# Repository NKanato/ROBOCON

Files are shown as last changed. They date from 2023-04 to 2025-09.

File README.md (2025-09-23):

# ROBOCON
ロボコン用リポジトリです。<br>
2023KYOROBO：2023年度九州共同ロボコン出場時の回路及びプログラム<br>
2023HONROBO：2023年度高専ロボコン出場時の回路及びプログラム<br>
の成果物を入れています。<br>
<br><br>
# 画像
2023九州共同ロボコン
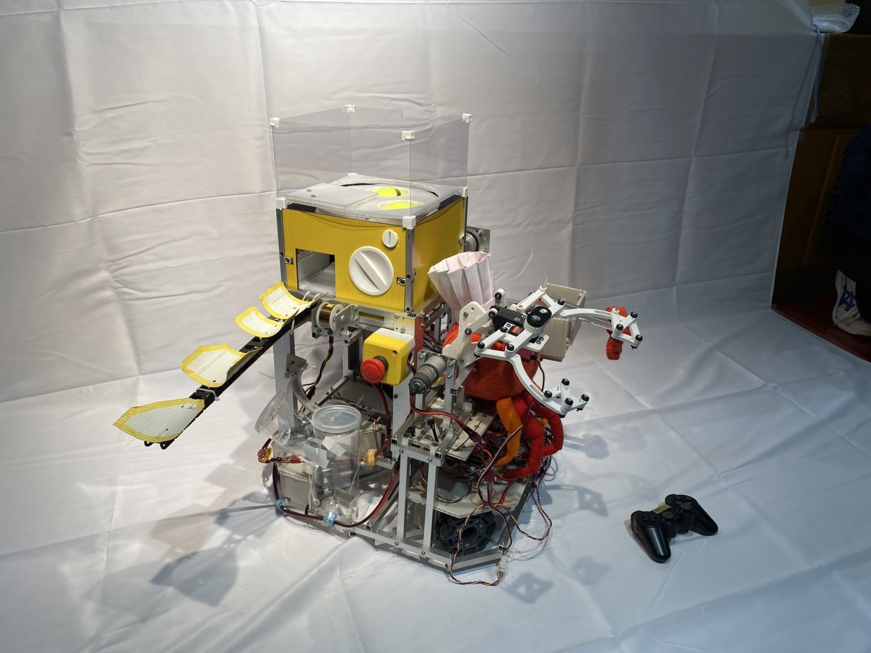
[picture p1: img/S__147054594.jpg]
2023九州共同ロボコン

<br><br>
2023高専ロボコン
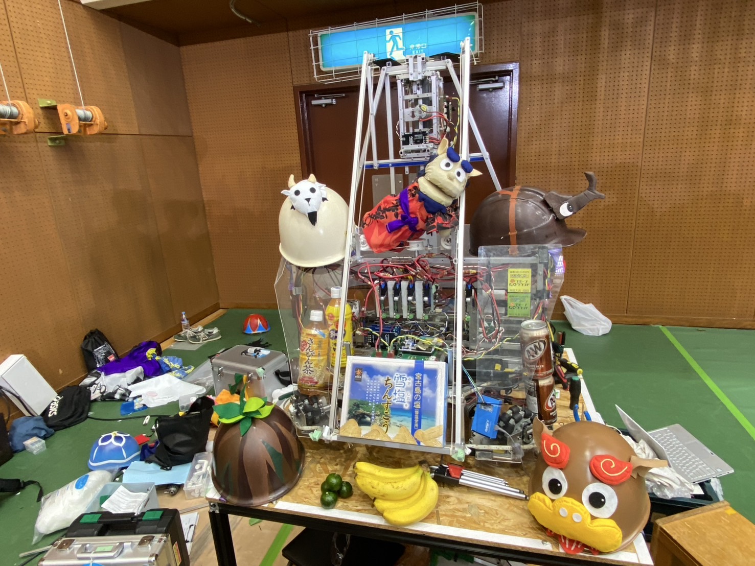
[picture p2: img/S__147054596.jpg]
2023高専ロボコン

<br><br>
# ディレクトリ構成
<pre>
├─2023HONROBO(2023年高専ロボコン)
│  ├─circuits
│  │  ├─CAN_bus(CAN通信バスをまとめる用)
│  │  │  └─can_bus
│  │  │      ├─canBus_plot
│  │  │      └─can_bus-backups
│  │  ├─main_board(メイン基板)
│  │  │  ├─ESP32_Devkit_V1.pretty
│  │  │  ├─main
│  │  │  └─main_board-backups
│  │  ├─undercarriage_system(足をまわり用基板)
│  │  │  ├─undercarriage2_plot
│  │  │  └─undercarriage_system-backups
│  │  └─undercarriage_system_thread(足をまわり用基板のモタドラスレッドver)
│  │      ├─plot
│  │      └─undercarriage_system-backups
│  └─sources
│      ├─2023_HONROBO_Harvest
│      ├─2023_HONROBO_main
│      └─2023_HONROBO_Wheels
└─2023KYOROBO(2023年九州共同ロボコン)
    ├─circuits
    │  ├─nucleo_446re.pretty
    │  └─NUCLEO_F446.pretty
    └─sources
</pre>
<br><br>
# 開発環境
| | |
| :-: | --- |
| OS(PC) | Windows 10 Pro |
| OS(マイコン) | mbed-os 5.15.7, 6.13.0 |
| IDE | Arm Keil Studio |
| HARD | NUCLEO-F446RE, NUCLEO-F303K8 |
| LANG | C++ |

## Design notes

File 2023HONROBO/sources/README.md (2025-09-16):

# NHK_2023_B_Manual

## Overview (概要)
- 2023Bチームの手動のプログラム群です。

## Directory (ディレクトリ構成)
```
.
├── 2023_HONROBO_Harvest(os 6.13.0, board F303K8)
├── 2023_HONROBO_Wheels (os 5.15.7, board F446RE)
├── 2023_HONROBO_main   (os 5.15.7, board F446RE)
└── README.md
```

## Environments (開発環境)
| | |
| :-: | --- |
| OS | Windows 10 Pro, mbed-os 5.15.7, 6.13.0 |
| IDE | Arm Keil Studio |
| HARD | NUCLEO-F446RE, NUCLEO-F303K8 |
| LANG | C++ |

---
<br>

## 概要
- 全てのマイコンは1本のCANバスを介して通信ができるようになっています。
- 2023_HONROBO_Harvest->収穫機構用のプログラムです。
- 2023_HONROBO_Wheels->足回り制御用のプログラムです。なぜか走行してると若干右回転するので、右側のオムニに補正をかけてあります。
- 2023_HONROBO_main->メインマイコン用のプログラムです。コントローラから受信した電文をここから他のマイコンへ送信します。

<br>

## 使用技術についてあれこれ
CANついて
- mbed-os5でCANの受信割り込みを使いたい場合は、InterfaceCAN.hとRawCAN.hを使う必要があります。ルートディレクトリに追加して使って下さい。(使い方は2023_HONROBO_Wheels/main.cpp参照)
- mbed-os6でCANの受信割り込みを使いたい場合は、特に何も追加する必要はありません。
- mbed2ではそもそもCANが使えませんでした。(リファンレスに使えるって載ってるのに...!)

超音波センサーについて
- 超音波センサーはURM37 v4.0というやつ(精度がいい)を使ってるので、その仕様に合わせて[チームメンバーが作ってくれたライブラリ](https://github.com/NITOkC-Robocon/ultrasonic-sensor-lib)を少し改変したものを使っています。

ジャイロについて
- 加速度のarc tanをとって機体の角度を割り出すと、値がぶっ飛びます。

<br>

## Author (リポジトリ作成者)
- [Kanato Nino](https://github.com/NKanato)

---

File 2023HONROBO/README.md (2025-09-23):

# 概要
2023年高専ロボコンで製作したロボットを制御するための回路とソースコードです。

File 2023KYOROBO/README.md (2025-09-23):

# 概要
2023年九州共同ロボコンのロボットの回路データとソースコードです。回路はエッチングで作ることを想定しています。

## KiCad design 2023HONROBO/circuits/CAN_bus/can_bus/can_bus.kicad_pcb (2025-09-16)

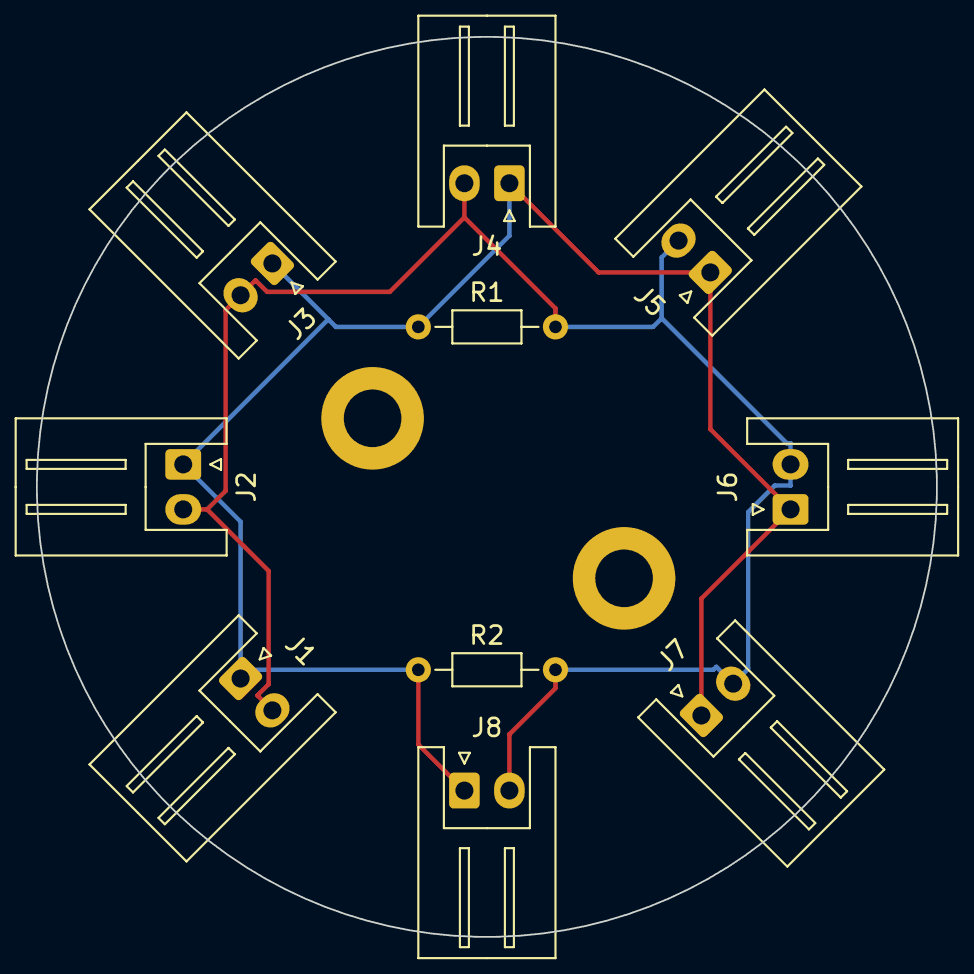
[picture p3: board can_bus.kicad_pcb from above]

Board: 2 copper layers, 50.0 x 50.0 mm, 12 parts (0 on the bottom side), 2 nets.

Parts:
H1, H2: MountingHole; MountingHole_3.2mm_M3_ISO7380_Pad
J1, J2, J3, J4, J5, J6, J7, J8: Conn_01x02_Female; JST_XH_S2B-XH-A_1x02_P2.50mm_Horizontal
R1, R2: R; R_Axial_DIN0204_L3.6mm_D1.6mm_P7.62mm_Horizontal

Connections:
unnamed: J1.1, J2.1, J3.1, J4.1, J5.1, J6.1, J7.1, J8.1, R1.1, R2.1
unnamed: J1.2, J2.2, J3.2, J4.2, J5.2, J6.2, J7.2, J8.2, R1.2, R2.2

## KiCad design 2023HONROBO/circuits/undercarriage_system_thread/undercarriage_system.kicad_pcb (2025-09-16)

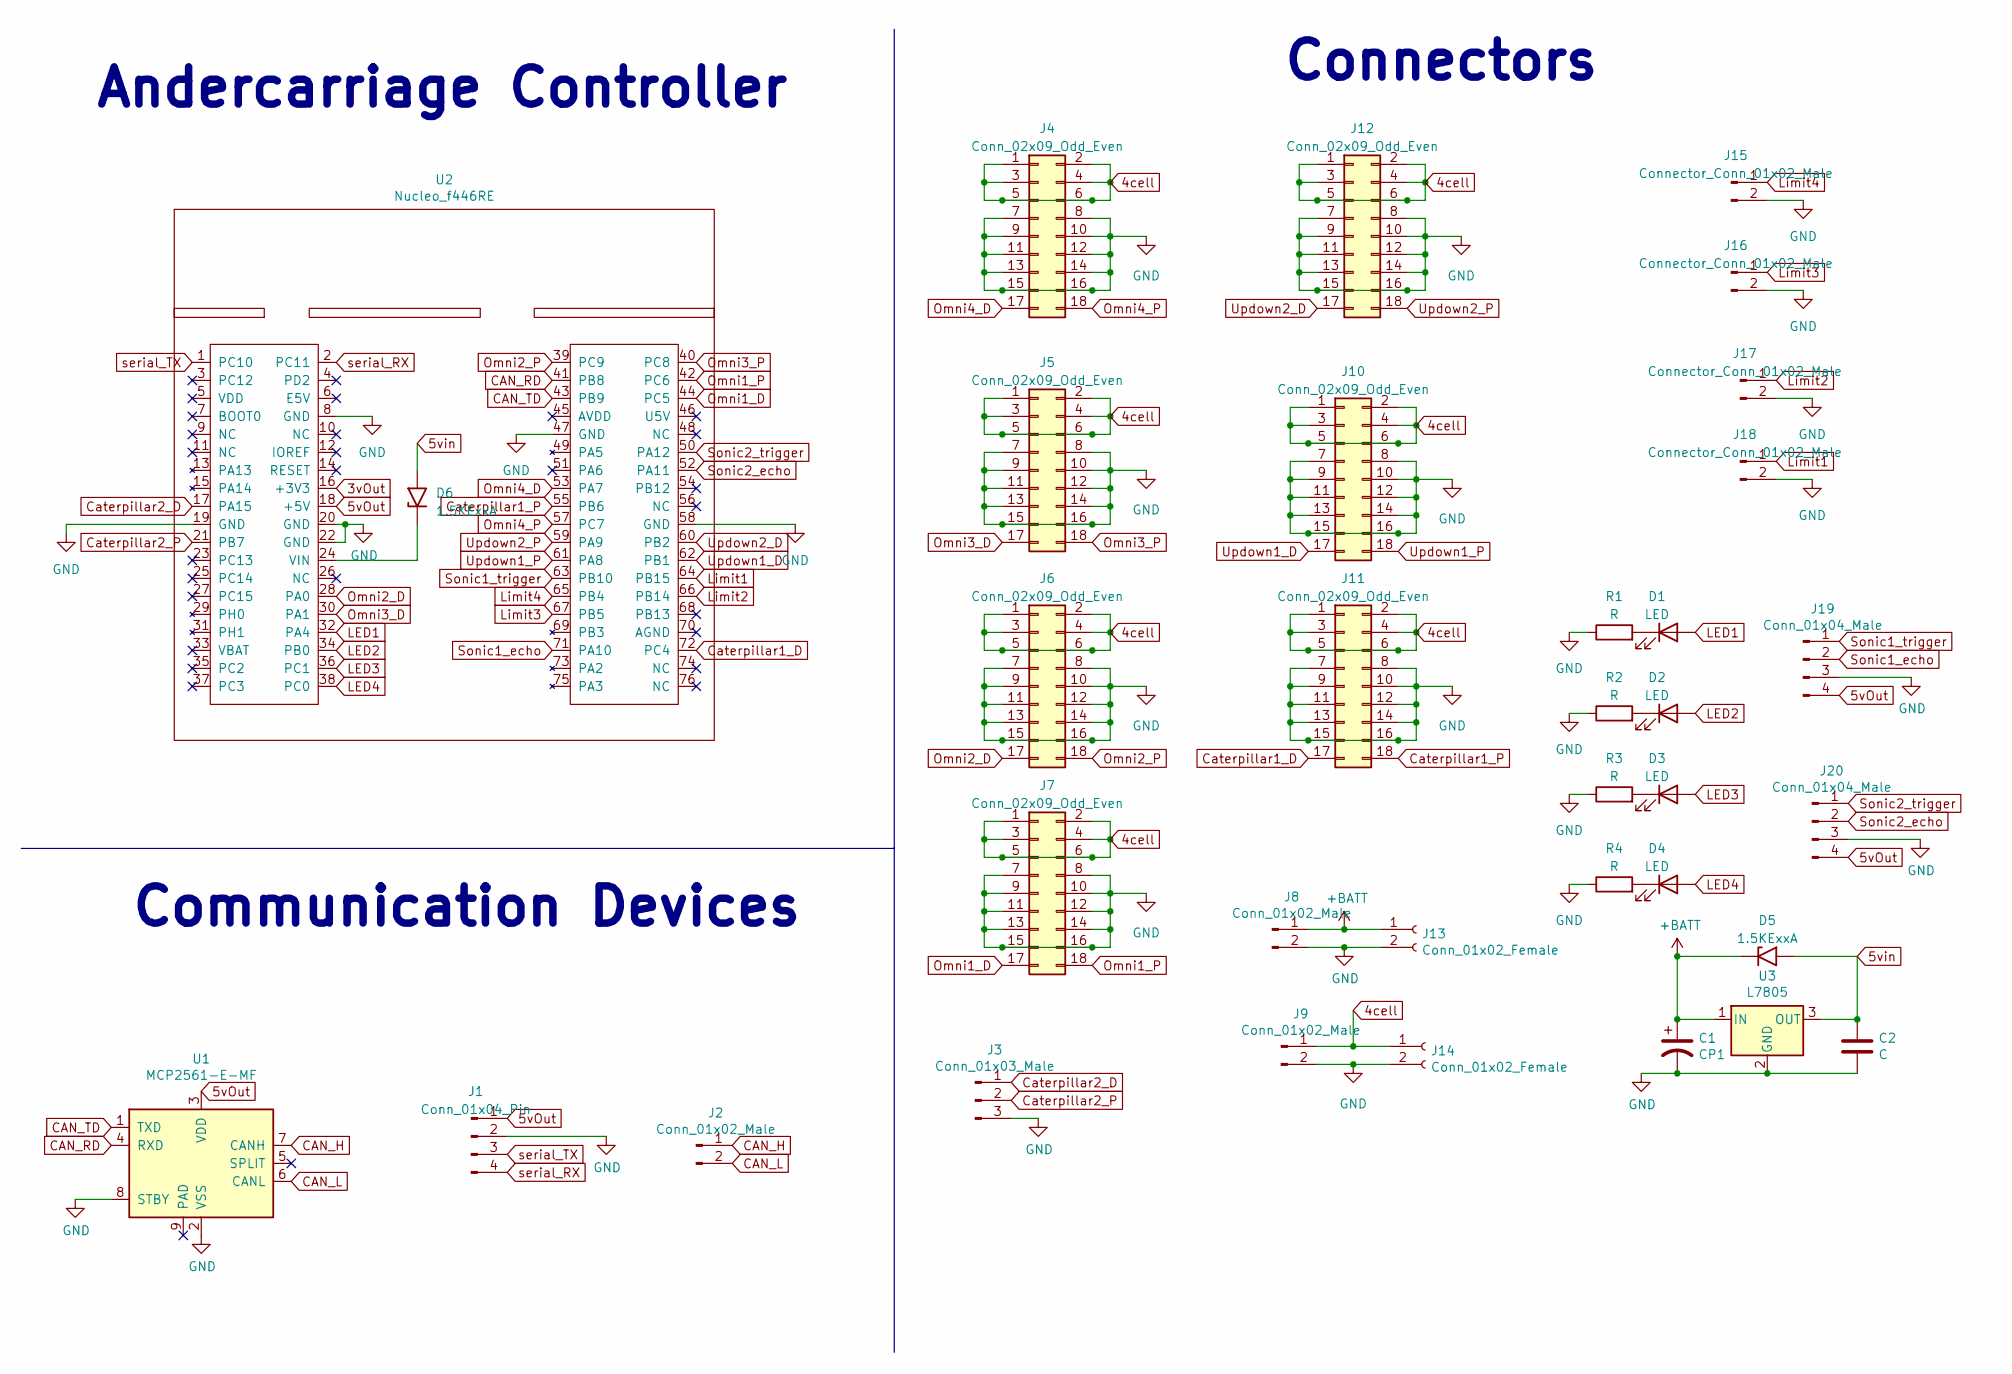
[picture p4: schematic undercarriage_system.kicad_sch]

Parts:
C1: CP1; CP_Radial_D6.3mm_P2.50mm
C2: C; C_Axial_L3.8mm_D2.6mm_P7.50mm_Horizontal
D1, D2, D3, D4: LED; LED_D3.0mm
D5, D6: 1.5KExxA; D_A-405_P7.62mm_Horizontal
J1: Conn_01x04_Pin; JST_XH_S4B-XH-A_1x04_P2.50mm_Horizontal
J2: Conn_01x02_Male; JST_XH_S2B-XH-A_1x02_P2.50mm_Horizontal
J3: Conn_01x03_Male; JST_XH_S3B-XH-A_1x03_P2.50mm_Horizontal
J4, J5, J6, J7, J10, J11, J12: Conn_02x09_Odd_Even; PinSocket_2x09_P2.54mm_Vertical
J8, J9: Conn_01x02_Male; Connector_T_Male
J13, J14: Conn_01x02_Female; Connector_T_Female
J15, J16, J17, J18: Connector_Conn_01x02_Male; JST_XH_S2B-XH-A_1x02_P2.50mm_Horizontal
J19, J20: Conn_01x04_Male; JST_XH_S4B-XH-A_1x04_P2.50mm_Horizontal
R1, R2, R3, R4: R; R_Axial_DIN0204_L3.6mm_D1.6mm_P7.62mm_Horizontal
U1: MCP2561-E-MF; DIP-8_W7.62mm_Socket
U2: Nucleo_f446RE; Nucleof446re
U3: L7805; NJM7805FA

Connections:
3vOut: U2.16 (+3V3)
4cell: J4.1, J4.2, J4.3, J4.4, J4.5, J4.6, J5.1, J5.2, J5.3, J5.4, J5.5, J5.6, J6.1, J6.2, J6.3, J6.4, J6.5, J6.6, J7.1, J7.2, J7.3, J7.4, J7.5, J7.6, J9.1, J10.1, J10.2, J10.3, J10.4, J10.5, J10.6, J11.1, J11.2, J11.3, J11.4, J11.5, J11.6, J12.1, J12.2, J12.3, J12.4, J12.5, J12.6, J14.1
5vOut: J1.1, J19.4, J20.4, U1.3 (VDD), U2.18 (+5V)
5vin: C2.1, D5.2 (A2), D6.2 (A2), U3.3 (OUT)
+BATT: C1.1, D5.1 (A1), J8.1, J13.1, U3.1 (IN)
CAN_RD: U1.4 (RXD), U2.41 (PB8)
CAN_TD: U1.1 (TXD), U2.43 (PB9)
Caterpillar1_D: J11.17, U2.72 (PC4)
Caterpillar1_P: J11.18, U2.55 (PB6)
Caterpillar2_D: J3.1, U2.17 (PA15)
Caterpillar2_P: J3.2, U2.21 (PB7)
GND: C1.2, C2.2, J1.2, J3.3, J4.7, J4.8, J4.9, J4.10, J4.11, J4.12, J4.13, J4.14, J4.15, J4.16, J5.7, J5.8, J5.9, J5.10, J5.11, J5.12, J5.13, J5.14, J5.15, J5.16, J6.7, J6.8, J6.9, J6.10, J6.11, J6.12, J6.13, J6.14, J6.15, J6.16, J7.7, J7.8, J7.9, J7.10, J7.11, J7.12, J7.13, J7.14, J7.15, J7.16, J8.2, J9.2, J10.7, J10.8, J10.9, J10.10, J10.11, J10.12, J10.13, J10.14, J10.15, J10.16, J11.7, J11.8, J11.9, J11.10, J11.11, J11.12, J11.13, J11.14, J11.15, J11.16, J12.7, J12.8, J12.9, J12.10, J12.11, J12.12, J12.13, J12.14, J12.15, J12.16, J13.2, J14.2, J15.2, J16.2, J17.2, J18.2, J19.3, J20.3, R1.1, R2.1, R3.1, R4.1, U1.2 (VSS), U1.8 (STBY), U2.8 (GND), U2.19 (GND), U2.20 (GND), U2.22 (GND), U2.47 (GND), U2.58 (GND), U3.2 (GND)
LED1: D1.2 (A), U2.32 (PA4)
LED2: D2.2 (A), U2.34 (PB0)
LED3: D3.2 (A), U2.36 (PC1)
LED4: D4.2 (A), U2.38 (PC0)
Limit1: J18.1, U2.64 (PB15)
Limit2: J17.1, U2.66 (PB14)
Limit3: J16.1, U2.67 (PB5)
Limit4: J15.1, U2.65 (PB4)
unnamed: D1.1 (K), R1.2
unnamed: D2.1 (K), R2.2
unnamed: D3.1 (K), R3.2
unnamed: D4.1 (K), R4.2
unnamed: D6.1 (A1), U2.24 (VIN)
Omni1_D: J7.17, U2.44 (PC5)
Omni1_P: J7.18, U2.42 (PC6)
Omni2_D: J6.17, U2.28 (PA0)
Omni2_P: J6.18, U2.39 (PC9)
Omni3_D: J5.17, U2.30 (PA1)
Omni3_P: J5.18, U2.40 (PC8)
Omni4_D: J4.17, U2.53 (PA7)
Omni4_P: J4.18, U2.57 (PC7)
Sonic1_echo: J19.2, U2.71 (PA10)
Sonic1_trigger: J19.1, U2.63 (PB10)
Sonic2_echo: J20.2, U2.52 (PA11)
Sonic2_trigger: J20.1, U2.50 (PA12)
Updown1_D: J10.17, U2.62 (PB1)
Updown1_P: J10.18, U2.61 (PA8)
Updown2_D: J12.17, U2.60 (PB2)
Updown2_P: J12.18, U2.59 (PA9)
serial_RX: J1.4, U2.2 (PC11)
serial_TX: J1.3, U2.1 (PC10)

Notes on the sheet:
Connectors
Communication Devices
Andercarriage Controller

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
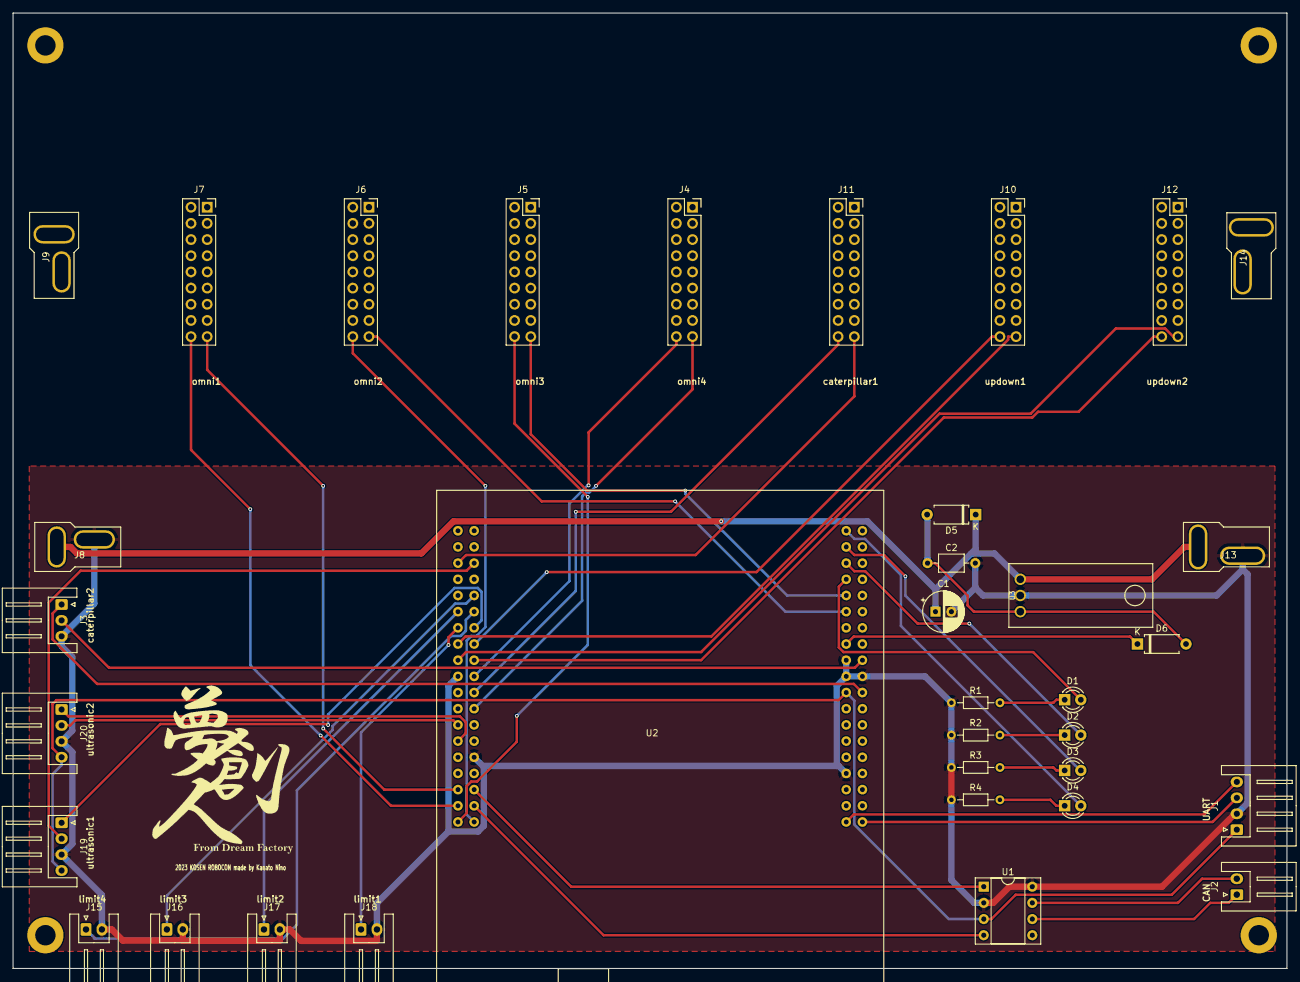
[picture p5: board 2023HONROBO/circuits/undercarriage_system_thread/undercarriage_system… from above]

Board: 2 copper layers, 200.0 x 150.0 mm, 35 parts (0 on the bottom side), 44 nets.

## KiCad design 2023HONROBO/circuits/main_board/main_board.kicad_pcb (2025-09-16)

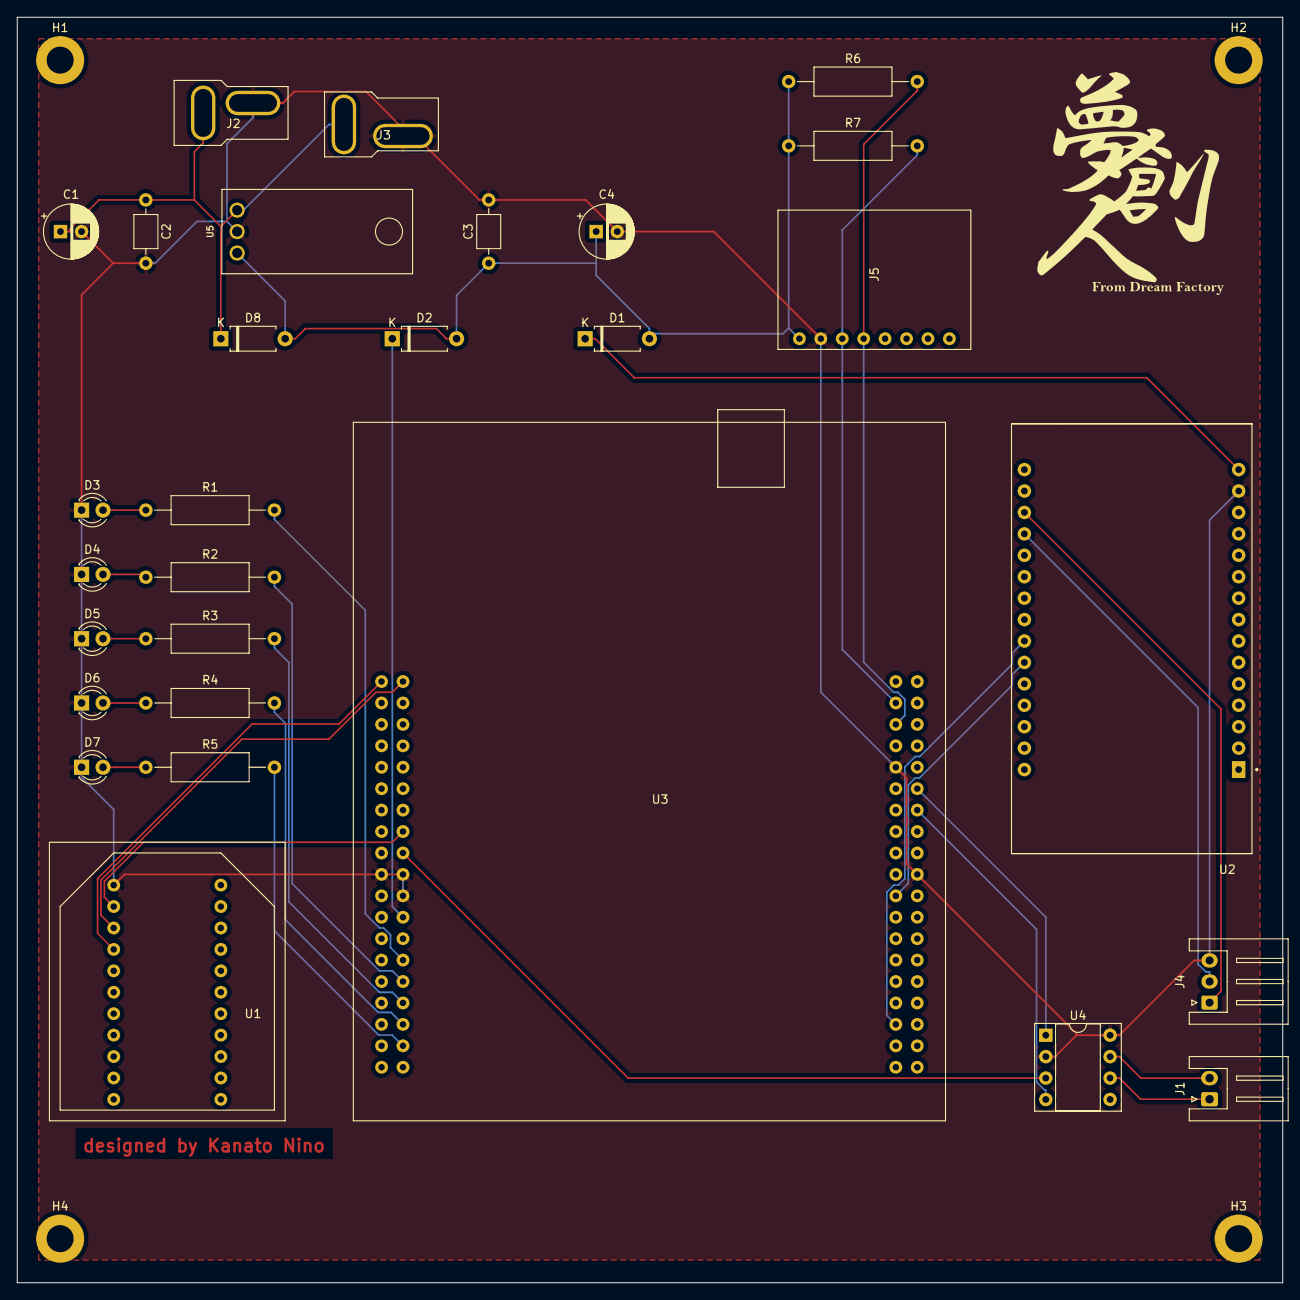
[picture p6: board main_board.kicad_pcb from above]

Board: 2 copper layers, 150.0 x 150.0 mm, 33 parts (0 on the bottom side), 29 nets.

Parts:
C1, C4: CP1; CP_Radial_D6.3mm_P2.50mm
C2, C3: C; C_Axial_L3.8mm_D2.6mm_P7.50mm_Horizontal
D1, D2, D8: 1.5KExxA; D_A-405_P7.62mm_Horizontal
D3, D4, D5, D6, D7: LED; LED_D3.0mm
H1, H2, H3, H4: MountingHole; MountingHole_3.2mm_M3_ISO7380_Pad
J1: Conn_01x02_Male; JST_XH_S2B-XH-A_1x02_P2.50mm_Horizontal
J2: Conn_01x02_Male; Connector_T_Male
J3: Conn_01x02_Female; Connector_T_Female
J4: Conn_01x03_Male; JST_XH_S3B-XH-A_1x03_P2.50mm_Horizontal
J5: Conn_01x08_Pin; GY=521
R1, R2, R3, R4, R5, R6, R7: R; R_Axial_DIN0309_L9.0mm_D3.2mm_P15.24mm_Horizontal
U1: xbeepros1; xbee_pro_s1
U2: ESP32_3-Pin; MODULE_ESP32_DEVKIT_V1
U3: Nucleo_f446RE; Nucleof446re
U4: MCP2561-E-MF; DIP-8_W7.62mm_Socket
U5: L7805; NJM7805FA

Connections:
3vOut: U1.2 (3.3v), U3.16 (+3V3)
5vOut: U3.18 (+5V), U4.3 (VDD)
5vin: C3.1, C4.1, D1.2 (A2), D2.2 (A2), D8.2 (A2), J5.1, R6.1, R7.1, U5.3 (OUT)
+BATT: C1.1, C2.1, D8.1 (A1), J2.1, J3.1, U5.1 (IN)
CAN1_RD: U3.52 (PA11), U4.4 (RXD)
CAN1_TD: U3.50 (PA12), U4.1 (TXD)
CAN_H: J1.2, U4.7 (CANH)
CAN_L: J1.1, U4.6 (CANL)
ESP32_RX: U2.24 (GPIO17), U3.71 (PA10)
ESP32_TX: U2.25 (GPIO16), U3.59 (PA9)
GND: C1.2, C2.2, C3.2, C4.2, D3.1 (K), D4.1 (K), D5.1 (K), D6.1 (K), D7.1 (K), J2.2, J3.2, J4.3, J5.2, U1.1 (gnd), U2.14 (GND), U3.19 (GND), U3.20 (GND), U3.22 (GND), U3.47 (GND), U3.58 (GND), U4.2 (VSS), U4.8 (STBY), U5.2 (GND)
I2C1_SCL: J5.3, R7.2, U3.41 (PB8)
I2C1_SDA: J5.4, R6.2, U3.43 (PB9)
LED1: R1.2, U3.28 (PA0)
LED2: R2.2, U3.30 (PA1)
LED3: R3.2, U3.32 (PA4)
LED4: R4.2, U3.34 (PB0)
LED5: R5.2, U3.36 (PC1)
unnamed: D1.1 (A1), U2.15 (5V)
unnamed: D2.1 (A1), U3.24 (VIN)
unnamed: D3.2 (A), R1.1
unnamed: D4.2 (A), R2.1
unnamed: D5.2 (A), R3.1
unnamed: D6.2 (A), R4.1
unnamed: D7.2 (A), R5.1
PS3_RX: U1.3 (out), U3.2 (PC11)
PS3_TX: U1.4 (in), U3.1 (PC10)
stop_RX: J4.2, U2.19 (RXD0)
stop_TX: J4.1, U2.18 (TXD0)

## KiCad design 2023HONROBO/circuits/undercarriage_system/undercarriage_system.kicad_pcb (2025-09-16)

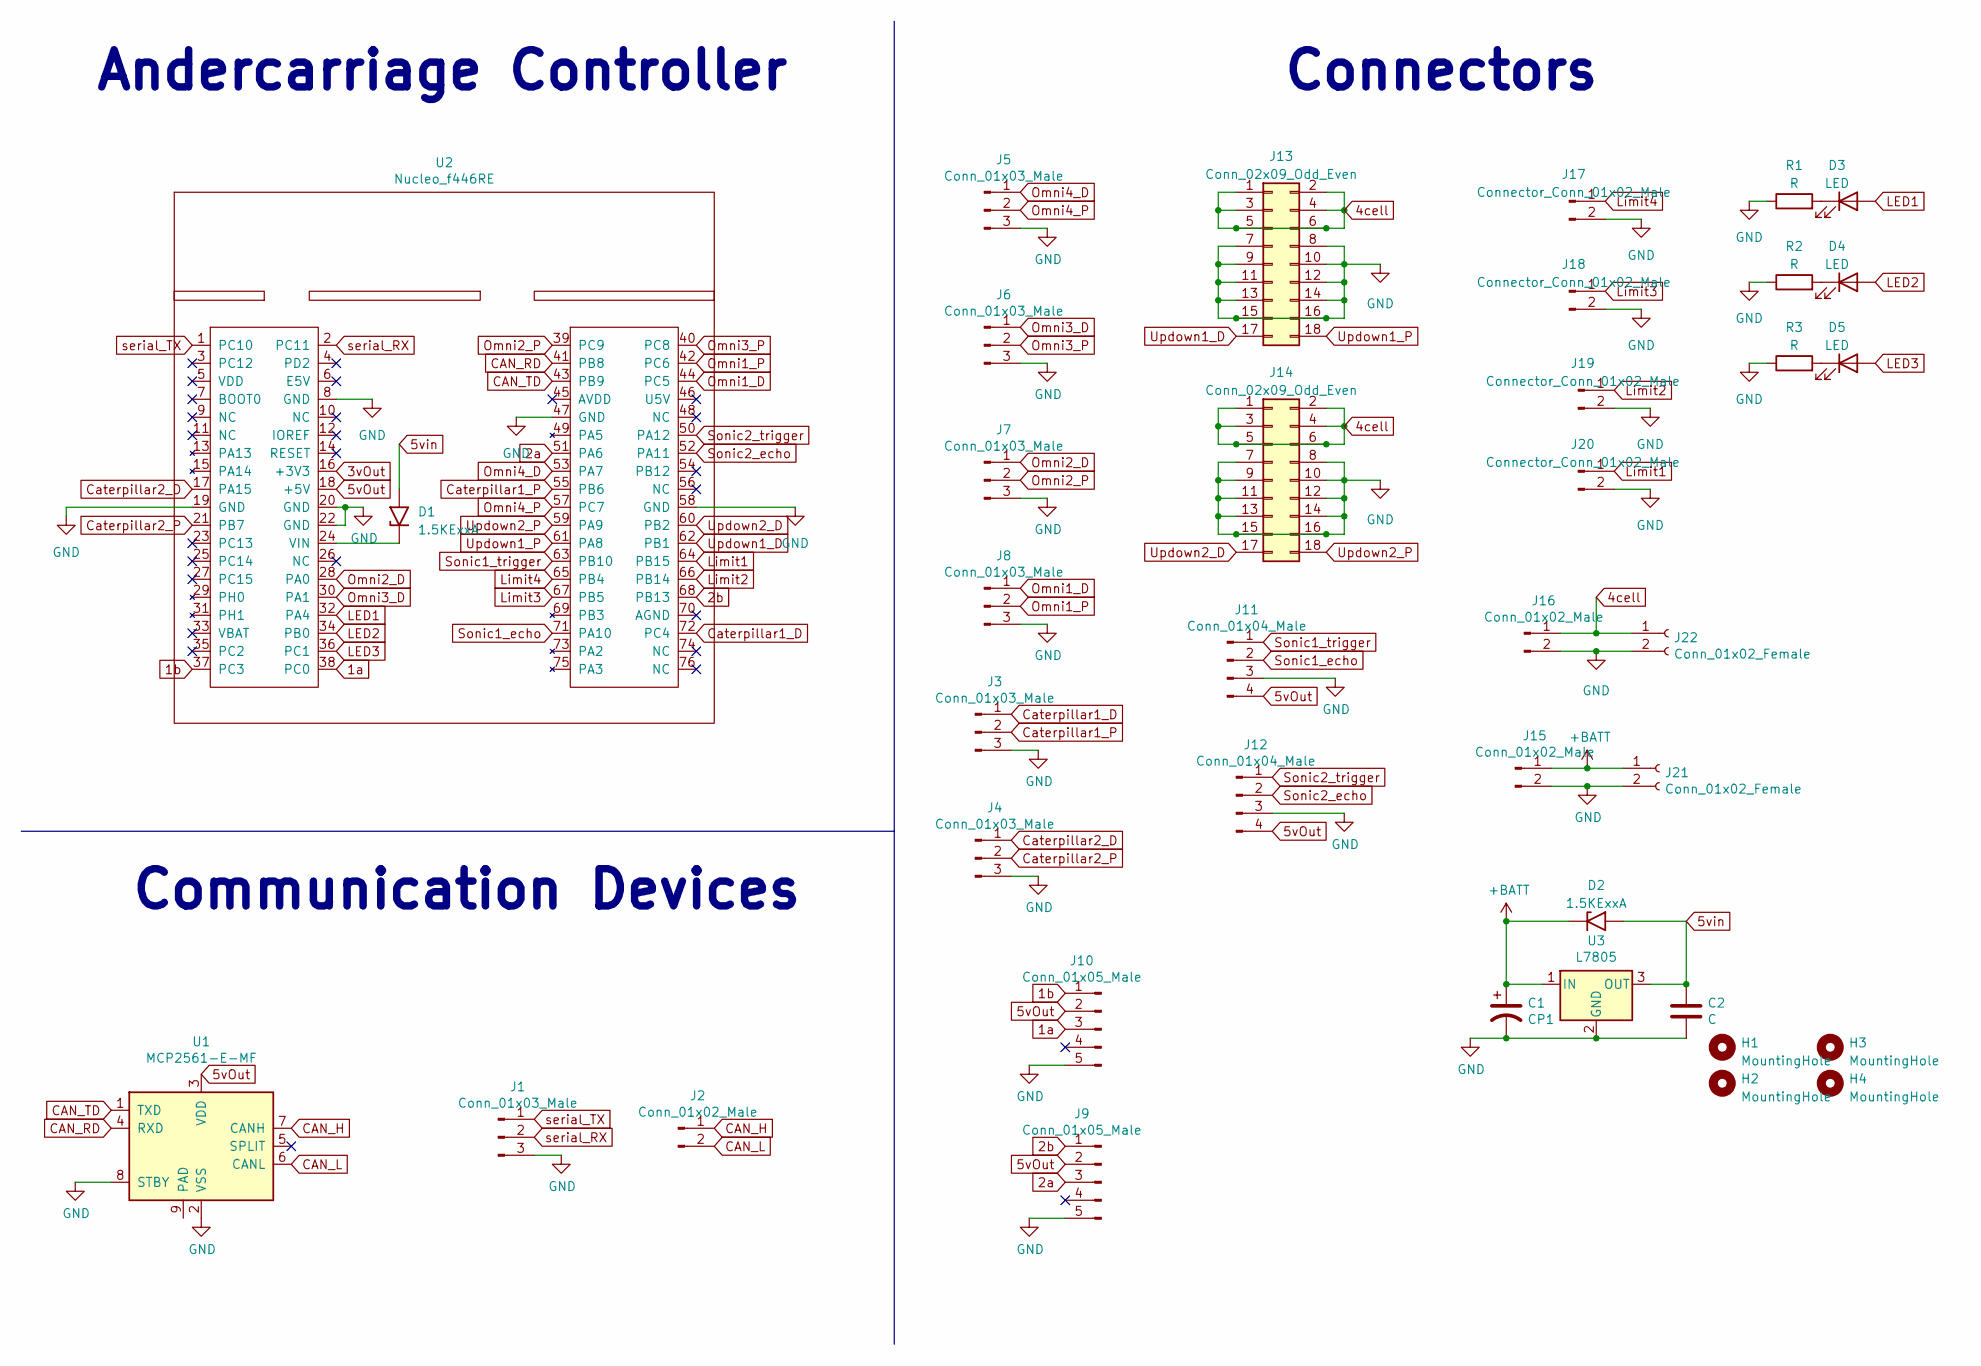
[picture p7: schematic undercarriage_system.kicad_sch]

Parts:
C1: CP1; CP_Radial_D6.3mm_P2.50mm
C2: C; C_Axial_L3.8mm_D2.6mm_P7.50mm_Horizontal
D1, D2: 1.5KExxA; D_A-405_P7.62mm_Horizontal
D3, D4, D5: LED; LED_D3.0mm
H1, H2, H3, H4: MountingHole; MountingHole_3.2mm_M3_ISO7380_Pad
J1, J3, J4, J5, J6, J7, J8: Conn_01x03_Male; JST_XH_S3B-XH-A_1x03_P2.50mm_Horizontal
J2: Conn_01x02_Male; JST_XH_S2B-XH-A_1x02_P2.50mm_Horizontal
J9, J10: Conn_01x05_Male; JST_XH_S5B-XH-A_1x05_P2.50mm_Horizontal
J11, J12: Conn_01x04_Male; JST_XH_S4B-XH-A_1x04_P2.50mm_Horizontal
J13, J14: Conn_02x09_Odd_Even; PinSocket_2x09_P2.54mm_Vertical
J15, J16: Conn_01x02_Male; Connector_T_Male
J17, J18, J19, J20: Connector_Conn_01x02_Male; JST_XH_S2B-XH-A_1x02_P2.50mm_Horizontal
J21, J22: Conn_01x02_Female; Connector_T_Female
R1, R2, R3: R; R_Axial_DIN0204_L3.6mm_D1.6mm_P7.62mm_Horizontal
U1: MCP2561-E-MF; DIP-8_W7.62mm_Socket
U2: Nucleo_f446RE; Nucleof446re
U3: L7805; NJM7805FA

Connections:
1a: J10.3, U2.38 (PC0)
1b: J10.1, U2.37 (PC3)
2a: J9.3, U2.51 (PA6)
2b: J9.1, U2.68 (PB13)
3vOut: U2.16 (+3V3)
4cell: J13.1, J13.2, J13.3, J13.4, J13.5, J13.6, J14.1, J14.2, J14.3, J14.4, J14.5, J14.6, J16.1, J22.1
5vOut: J9.2, J10.2, J11.4, J12.4, U1.3 (VDD), U2.18 (+5V)
5vin: C2.1, D1.2 (A2), D2.2 (A2), U3.3 (OUT)
+BATT: C1.1, D2.1 (A1), J15.1, J21.1, U3.1 (IN)
CAN_H: J2.1, U1.7 (CANH)
CAN_L: J2.2, U1.6 (CANL)
CAN_RD: U1.4 (RXD), U2.41 (PB8)
CAN_TD: U1.1 (TXD), U2.43 (PB9)
Caterpillar1_D: J3.1, U2.72 (PC4)
Caterpillar1_P: J3.2, U2.55 (PB6)
Caterpillar2_D: J4.1, U2.17 (PA15)
Caterpillar2_P: J4.2, U2.21 (PB7)
GND: C1.2, C2.2, J1.3, J3.3, J4.3, J5.3, J6.3, J7.3, J8.3, J9.5, J10.5, J11.3, J12.3, J13.7, J13.8, J13.9, J13.10, J13.11, J13.12, J13.13, J13.14, J13.15, J13.16, J14.7, J14.8, J14.9, J14.10, J14.11, J14.12, J14.13, J14.14, J14.15, J14.16, J15.2, J16.2, J17.2, J18.2, J19.2, J20.2, J21.2, J22.2, R1.1, R2.1, R3.1, U1.2 (VSS), U1.8 (STBY), U2.8 (GND), U2.19 (GND), U2.20 (GND), U2.22 (GND), U2.47 (GND), U2.58 (GND), U3.2 (GND)
LED1: D3.2 (A), U2.32 (PA4)
LED2: D4.2 (A), U2.34 (PB0)
LED3: D5.2 (A), U2.36 (PC1)
Limit1: J20.1, U2.64 (PB15)
Limit2: J19.1, U2.66 (PB14)
Limit3: J18.1, U2.67 (PB5)
Limit4: J17.1, U2.65 (PB4)
unnamed: D1.1 (A1), U2.24 (VIN)
unnamed: D3.1 (K), R1.2
unnamed: D4.1 (K), R2.2
unnamed: D5.1 (K), R3.2
Omni1_D: J8.1, U2.44 (PC5)
Omni1_P: J8.2, U2.42 (PC6)
Omni2_D: J7.1, U2.28 (PA0)
Omni2_P: J7.2, U2.39 (PC9)
Omni3_D: J6.1, U2.30 (PA1)
Omni3_P: J6.2, U2.40 (PC8)
Omni4_D: J5.1, U2.53 (PA7)
Omni4_P: J5.2, U2.57 (PC7)
Sonic1_echo: J11.2, U2.71 (PA10)
Sonic1_trigger: J11.1, U2.63 (PB10)
Sonic2_echo: J12.2, U2.52 (PA11)
Sonic2_trigger: J12.1, U2.50 (PA12)
Updown1_D: J13.17, U2.62 (PB1)
Updown1_P: J13.18, U2.61 (PA8)
Updown2_D: J14.17, U2.60 (PB2)
Updown2_P: J14.18, U2.59 (PA9)
serial_RX: J1.2, U2.2 (PC11)
serial_TX: J1.1, U2.1 (PC10)

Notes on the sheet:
Connectors
Communication Devices
Andercarriage Controller

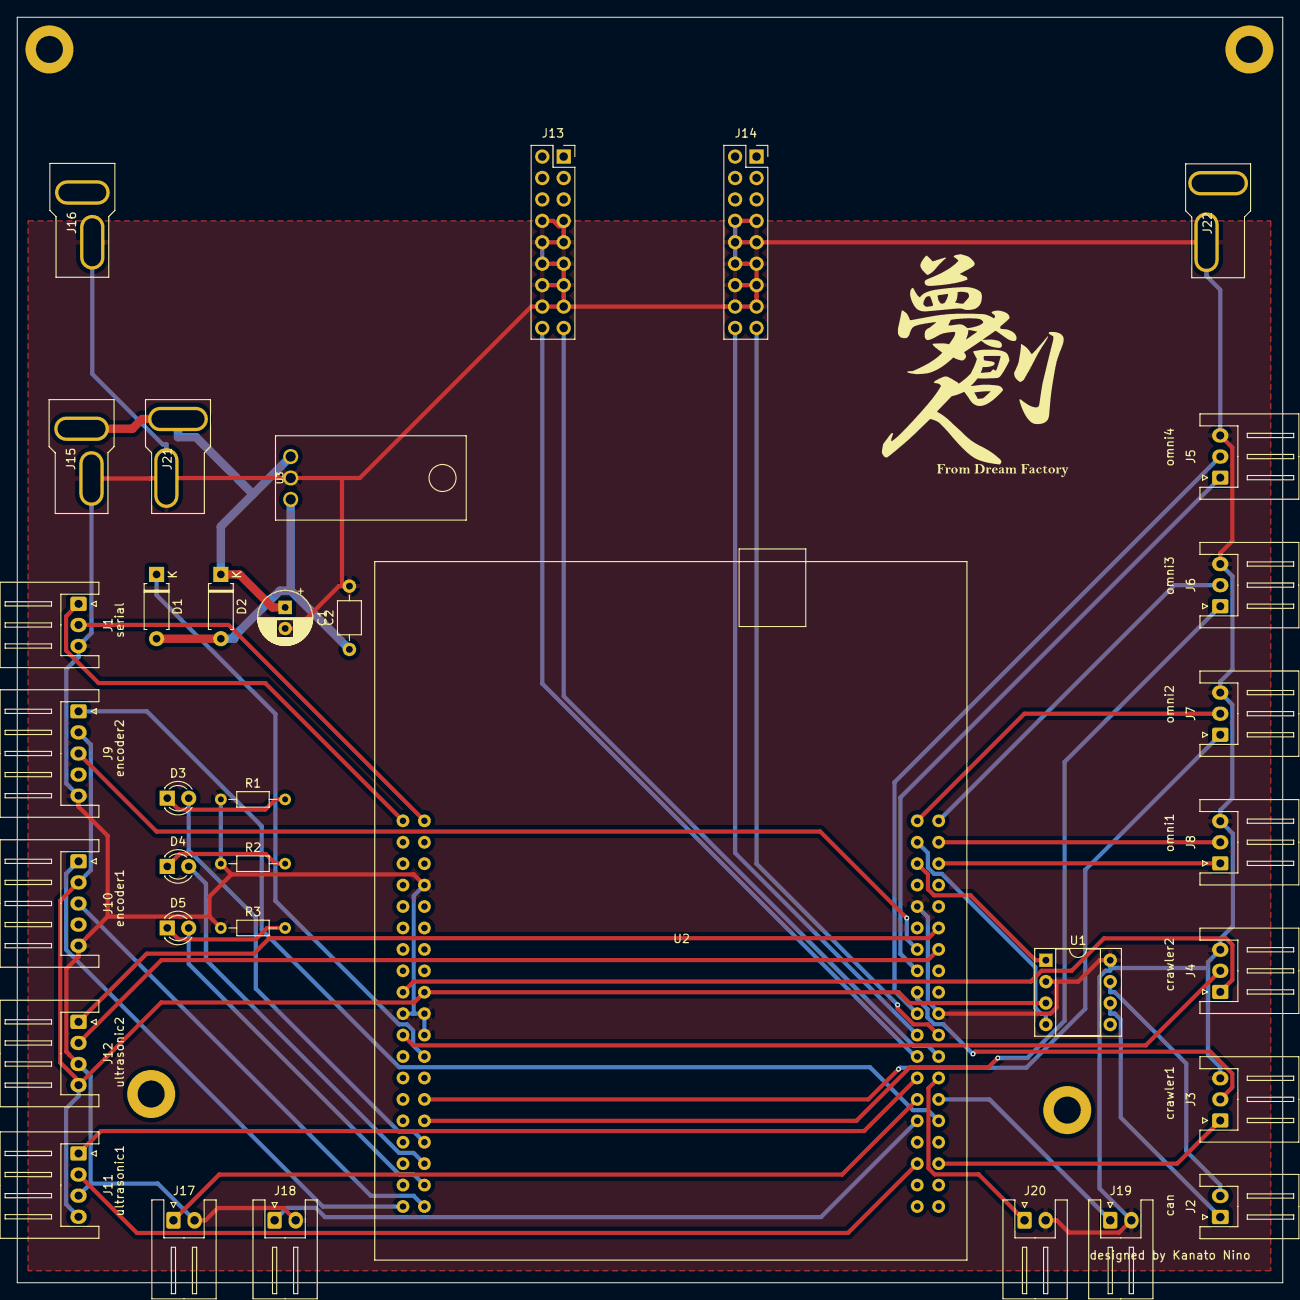
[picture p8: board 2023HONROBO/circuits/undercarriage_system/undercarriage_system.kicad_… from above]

Board: 2 copper layers, 150.0 x 150.0 mm, 39 parts (0 on the bottom side), 46 nets.

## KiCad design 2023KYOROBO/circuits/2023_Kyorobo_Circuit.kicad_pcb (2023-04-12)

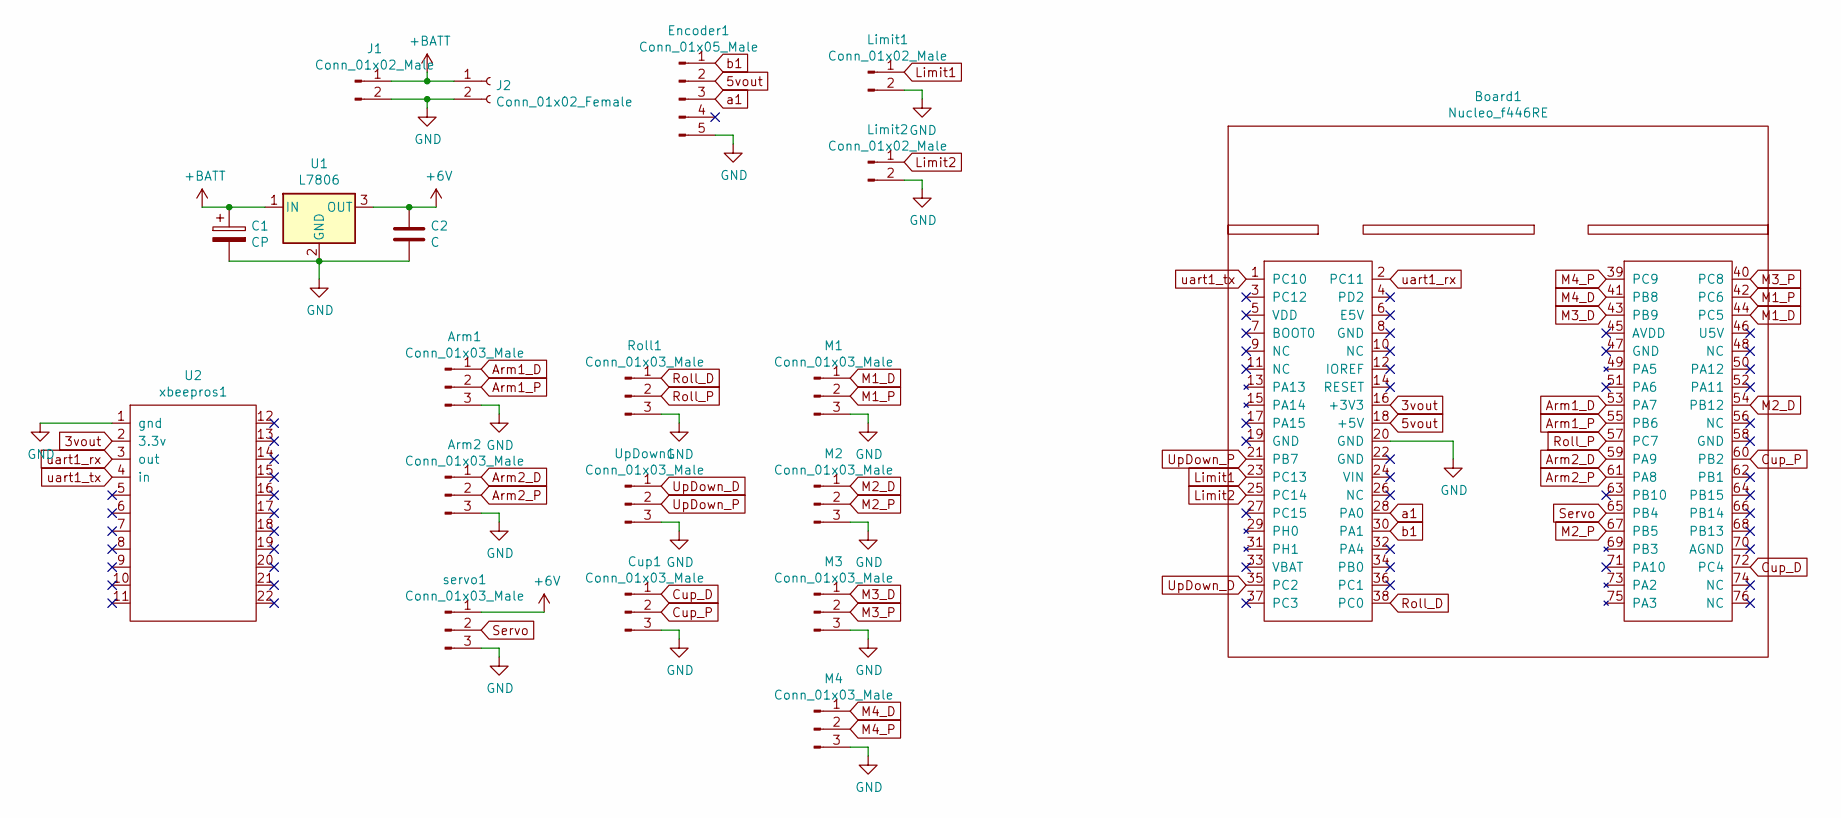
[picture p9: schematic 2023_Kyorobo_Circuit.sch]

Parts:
Arm1, Arm2: Conn_01x03_Male; JST_XH_S3B-XH-A-1_1x03_P2.50mm_Horizontal
Board1: Nucleo_f446RE; Nucleof446re
C1: CP; CP_Radial_D7.5mm_P2.50mm
C2: C; C_Axial_L3.8mm_D2.6mm_P7.50mm_Horizontal
Cup1: Conn_01x03_Male; JST_XH_S3B-XH-A-1_1x03_P2.50mm_Horizontal
Encoder1: Conn_01x05_Male; JST_XH_S5B-XH-A-1_1x05_P2.50mm_Horizontal
J1: Conn_01x02_Male; Connector_T_Male
J2: Conn_01x02_Female; Connector_T_Female
Limit1, Limit2: Conn_01x02_Male; JST_XH_S2B-XH-A-1_1x02_P2.50mm_Horizontal
M1, M2, M3, M4: Conn_01x03_Male; JST_XH_S3B-XH-A-1_1x03_P2.50mm_Horizontal
Roll1: Conn_01x03_Male; JST_XH_S3B-XH-A-1_1x03_P2.50mm_Horizontal
U1: L7806; NJM7805FA
U2: xbeepros1; xbee_pro_s1
UpDown1: Conn_01x03_Male; JST_XH_S3B-XH-A-1_1x03_P2.50mm_Horizontal
servo1: Conn_01x03_Male; JST_XH_S3B-XH-A-1_1x03_P2.50mm_Horizontal

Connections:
3vout: Board1.16 (+3V3), U2.2 (3.3v)
5vout: Board1.18 (+5V), Encoder1.2
+6V: C2.1, U1.3 (OUT), servo1.1
+BATT: C1.1, J1.1, J2.1, U1.1 (IN)
Arm1_D: Arm1.1, Board1.53 (PA7)
Arm1_P: Arm1.2, Board1.55 (PB6)
Arm2_D: Arm2.1, Board1.59 (PA9)
Arm2_P: Arm2.2, Board1.61 (PA8)
Cup_D: Board1.72 (PC4), Cup1.1
Cup_P: Board1.60 (PB2), Cup1.2
GND: Arm1.3, Arm2.3, Board1.20 (GND), C1.2, C2.2, Cup1.3, Encoder1.5, J1.2, J2.2, Limit1.2, Limit2.2, M1.3, M2.3, M3.3, M4.3, Roll1.3, U1.2 (GND), U2.1 (gnd), UpDown1.3, servo1.3
Limit1: Board1.23 (PC13), Limit1.1
Limit2: Board1.25 (PC14), Limit2.1
M1_D: Board1.44 (PC5), M1.1
M1_P: Board1.42 (PC6), M1.2
M2_D: Board1.54 (PB12), M2.1
M2_P: Board1.67 (PB5), M2.2
M3_D: Board1.43 (PB9), M3.1
M3_P: Board1.40 (PC8), M3.2
M4_D: Board1.41 (PB8), M4.1
M4_P: Board1.39 (PC9), M4.2
Roll_D: Board1.38 (PC0), Roll1.1
Roll_P: Board1.57 (PC7), Roll1.2
Servo: Board1.65 (PB4), servo1.2
UpDown_D: Board1.35 (PC2), UpDown1.1
UpDown_P: Board1.21 (PB7), UpDown1.2
a1: Board1.28 (PA0), Encoder1.3
b1: Board1.30 (PA1), Encoder1.1
uart1_rx: Board1.2 (PC11), U2.3 (out)
uart1_tx: Board1.1 (PC10), U2.4 (in)

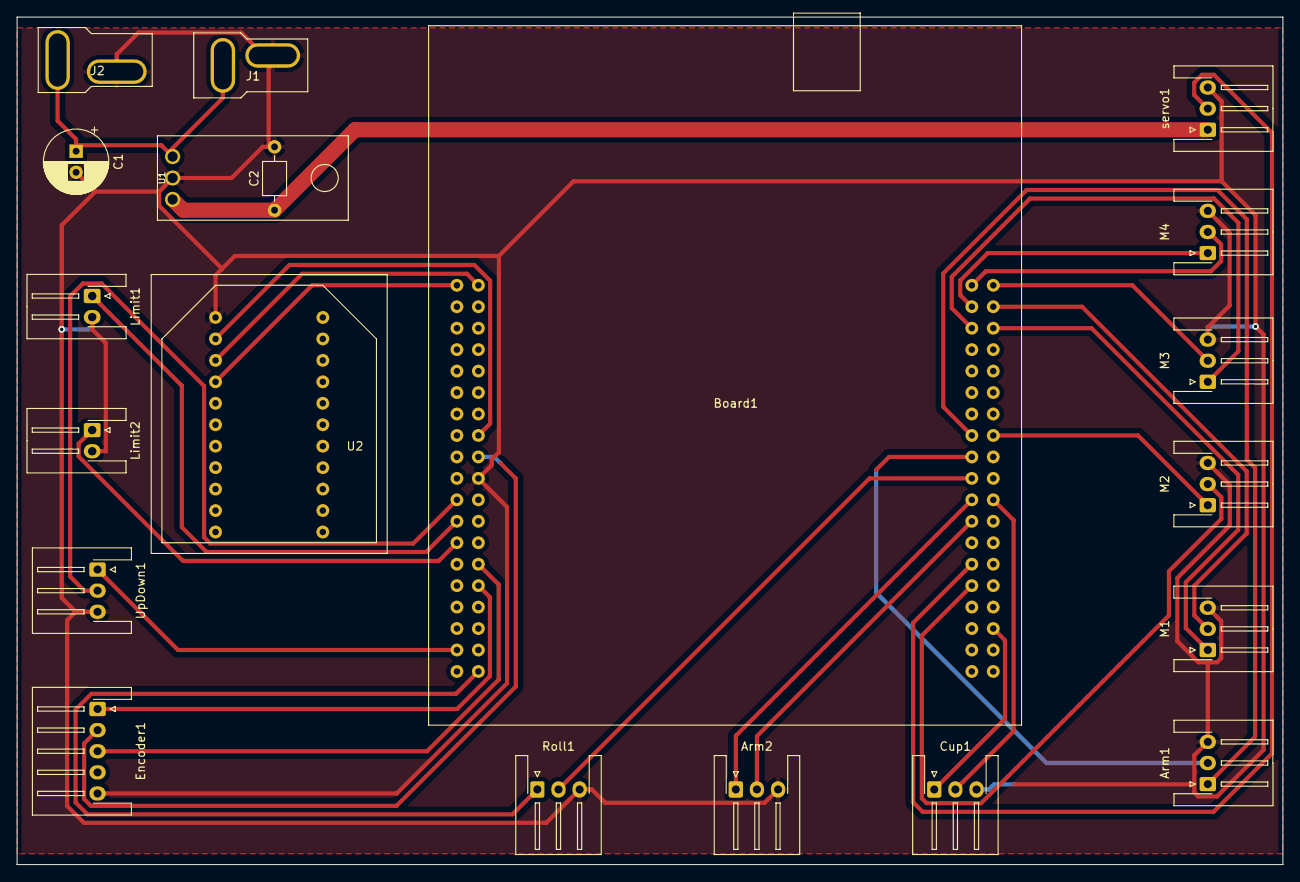
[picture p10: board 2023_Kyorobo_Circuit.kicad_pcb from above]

Board: 2 copper layers, 149.9 x 100.3 mm, 20 parts (0 on the bottom side), 30 nets.

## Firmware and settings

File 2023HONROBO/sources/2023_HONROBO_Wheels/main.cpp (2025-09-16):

/*
 * 2023 NHK KOSEN ROBOCON
 * Board        : Nucleo F446RE
 * OS           : mbed-os5.15.7
 * Created Date : May first 2023
 * Modified Date: August 11 2023
 * Author       : Kanato Nino@NIT Okinawa College
 *
 */

//ライブラリたち
#include <cmath>
#include <cstdint>
#include "mbed.h"
#include "RawCAN.h"
#include "RotaryEncoder.h"
#include "rtos.h"
#include "servo.h"
#include "ultrasonic.h"

//パラメータ設定
#define MAX_OMNI_SPEED 0.8
#define MIN_OMNI_SPEED 0.2
#define MAX_ROLL_SPEED 0.4
#define MIN_ROLL_SPEED 0.15
#define MAX_CATERPILLAR_SPEED 0.5
#define MIN_CATERPILLAR_SPEED 0.3
#define MAX_UPDOWN_SPEED 0.9
#define MIN_UPDOWN_SPEED 0.3
#define SWITCH_DISTANCE 80     //cm
#define MAX_HARVEST_SPEED 0.5
#define MAX_PROP_SPEED 0.7
#define MAX_RAIL_SPEED 1.0
#define MIN_RAIL_SPEED 0.8
#define ACCEL_TIME 5
#define RATE_ADJUST 0.01
#define END_ANGLE 13
#define CATERPILLAR_BREAK_TIME 3.0  //sec

#define NUM_OMNI 4
#define NUM_UPDOWN 2
#define NUM_LIMIT 4
#define NUM_SONIC_SENSOR 2
#define NUM_LED 3

#define PERIOD_OMNI 1275
#define PERIOD_UPDOWN 1275
#define PERIOD_CATERPILLAR 1275

#define CAN_SIZE 8
#define CAN_WHEEL_ID 1337
#define CAN_JETSON_ID 1339

#define mC 261.626
#define PI 3.1415926535


//ピン
DigitalOut omni_D[NUM_OMNI] = {
    DigitalOut(PC_5),
    DigitalOut(PA_0),
    DigitalOut(PA_1),
    DigitalOut(PA_7)
};

PwmOut omni_P[NUM_OMNI] = {
    PwmOut(PC_6),
    PwmOut(PC_9),
    PwmOut(PC_8),
    PwmOut(PC_7)
};

DigitalOut updown_D[NUM_UPDOWN] = {
    DigitalOut(PB_1),
    DigitalOut(PB_2)
};

PwmOut updown_P[NUM_UPDOWN] = {
    PwmOut(PA_8),
    PwmOut(PA_9)

};

DigitalOut caterpillar_D(PC_4);
PwmOut caterpillar_P(PB_6);


DigitalOut led[NUM_LED] = {
    DigitalOut(PA_4),   //起動
    DigitalOut(PB_0),   //jetsonとの通信ステータス
    DigitalOut(PC_1)    //canの受信ステータス
};

//リミットスイッチ
DigitalIn limit[NUM_LIMIT] = {
    DigitalIn(PB_15),
    DigitalIn(PB_14),
    DigitalIn(PB_5),
    DigitalIn(PB_4)
};

//エンコーダ
RotaryEncoder encoder_X(PC_0, PC_3);    //encoder1
RotaryEncoder encoder_Y(PA_6, PB_13);   //encoder2

//超音波センサー
Ultrasonic ultrasonic1(PB_10, PA_10);

//通信
RawSerial pc(USBTX,USBRX,115200);
RawSerial jetson(PC_10, PC_11, 9600);
RawCAN can(PB_8, PB_9);

//増設のモーター
DigitalOut rail_D(PA_15);
PwmOut rail_P(PB_7);
DigitalOut prop_D(PA_12);
PwmOut prop_P(PA_11);


void initWheels(void);                  //全体の初期化を行う
void initCan(void);                     //CAN初期化
inline void Config(void);               //割り込み設定
inline void JetsonData(void);           //Jetson(PC)の受信関数
void canData(void);                     //CANの受信用関数
inline void stopAllWheels(void);        //足回りを止める
inline void stopOmni(void);             //オムニを止める
int readDistance(void);                 //距離を測る
void shouldSwitch(void);                //上下するかどうか？
void caterpillarMove(int direction);    //キャタピラ動かす
void caterpillarUp(void);               //キャタピラ上昇
void caterpillarDown(void);             //キャタピラ下降
void omniAcceleration(void);            //オムニ加速
void omniSlowDown(void);                //オムニ減速

void omniMovedByJetson(void);           //オムニ自動用



//新しいオムニのコード
void omniGyro(void);
void accelControl(double *targetSpeed, int mode);
bool isPressed(unsigned char data, int bits);
double maxNum(double *num);

//グローバル変数
unsigned char Can[CAN_SIZE];
int16_t yaw = 0;
int slope = 0;
int JETSON[8];
double CURRENT_OMNI_SPEED;
double currentOmniSpeed[NUM_OMNI];
double motor[NUM_OMNI];
double Angle, Radial;
double Rotate;
int directionTmp = 0;
bool isOmniLocked = false;
bool isCaterpillarLocked = true;
double caterpiBreakTime = 0;

double omniSpeedTmp[NUM_OMNI];//Gyroomniの先頭から切り取り
uint8_t forwardTmp;
int angleStatus=0;

//その他
Timer timer,timer_w,timer_r;
Ticker ticker;          //タイマ割り込み
Thread thread;
CANMessage msg;


//---------
void backToPosition(double yaw){
    int i;
    while(true){
        if(yaw > 0){
            for(i = 0; i < 4; i++){
                omni_D[i] = 1;
                omni_P[i] = MIN_OMNI_SPEED;
                pc.printf("[RIGHT]");

            }
            break;
        }
        else if(yaw < 0){
            for(i = 0; i < 4; i++){
                omni_D[i] = 0;
                omni_P[i] = MIN_OMNI_SPEED;
                pc.printf("[LEFT]");
            }
            break;
        }
        else{
            for(i = 0; i < 4; i++){
                omni_P[i] = 0;
                pc.printf("[NONE]");
            }
            break;
        }
        pc.printf("\n\r");
    }
}
//--------


//ロープ超えるためのレール動かす
void moveRail(void){
    int i;
    if(Can[2] == 0x01){
        rail_D = 0;
        rail_P = MAX_RAIL_SPEED;
        pc.printf("up rail ");
    }
    else if(Can[5] == 0x20){
        rail_D = 1;
        rail_P = MIN_RAIL_SPEED;
        pc.printf("down rail ");
    }
    else{
        rail_P = 0;
    }
}
//--------


int main(void){
    int i,j;    //カウント用変数
    initWheels();
    int sw[NUM_LIMIT];

    //コントローラのL2,R2で起動されるまで待機
    while(Can[0] != 0x80){ pc.printf(" waiting \r"); }
    ThisThread::sleep_for(500);
    pc.printf("start!!\n\r");
    thread.start(shouldSwitch);

    for (i = 0; i < 8; i++){
        JETSON[i] = 0;
    }
    while(1){
        if(Can[0] == 0x80){
            if(Can[0] != 0x80){ led[0] = 0; }
            else{ led[0] = 1; }


            omniGyro();
            caterpillarMove(0);
            moveRail();
        }

        else if(Can[0] == 0x90){
            //jetsonへの通信来た時の処理を書く
            pc.printf("auto mode\n\r");

            if(Can[2] == 0x01){ jetson.putc(Can[2]); }      //送信1byte目
            else if(Can[2] == 0x02){ jetson.putc(Can[2]); }
            else{ jetson.putc(0x40); }

            if(Can[2] == 0x04){ jetson.putc(Can[2]); }      //送信2byte目
            else if(Can[2] == 0x08) { jetson.putc(Can[2]); }
            else{ jetson.putc(0x40); }
            jetson.putc(Can[3]);    //送った後の処理はわっしー担当
            //jetsonから通信が来た時の処理(自動で足動かす用)
            omniMovedByJetson();
        }
        for(i = 0;i < NUM_LIMIT; i++){
            sw[i] = limit[i];
        }
        pc.printf("id %d Can %d %d %d %d %d rderror: %d sw:%d%d%d%d\n\r", msg.id, Can[0], Can[1], Can[2], Can[3], Can[4], can.rderror(), sw[0], sw[1], sw[2], sw[3]);
        pc.printf("[[%d %d]] %d %d %d %d ", slope, yaw, sw[0], sw[1], sw[2], sw[3]);//9.24後で戻す
        pc.printf("\n\r");

        ThisThread::sleep_for(10);
    }

    return (0);
}


void caterpillarMove(int direction){    //キャタピラ動かす
    if(isCaterpillarLocked){
        caterpillar_P = 0;
        return;
    }
    pc.printf("caterpillarMove-> ");
    if(forwardTmp == 9 || JETSON[2] == 0x01){
        caterpillar_D = direction;
        if(!isOmniLocked){ caterpillar_P = MIN_CATERPILLAR_SPEED; }
        else{ caterpillar_P = MAX_CATERPILLAR_SPEED; }
    }
    else if(forwardTmp == 6 || JETSON[2] == 0x02){
        caterpillar_D = 1;
        if(!isOmniLocked){ caterpillar_P = MIN_CATERPILLAR_SPEED; }
        else{ caterpillar_P = MAX_CATERPILLAR_SPEED; }
    }
    else{
        caterpillar_P = 0;
    }
}


void shouldSwitch(void){     //キャタピラの切り替えを判断する関数
    double distance_F;
    pc.printf("thread start!!\n\r");
    while(true){
        distance_F = ultrasonic1.getDistance();  //前方の角材との距離
        pc.printf("<dist>%.2f <maxNum>%.2f", distance_F, maxNum(&omniSpeedTmp[0]));
        if(Can[2] != 0x02 && (distance_F <= SWITCH_DISTANCE) && (forwardTmp == 9 || forwardTmp == 6 || JETSON[2] == 0x01) && (maxNum(&omniSpeedTmp[0]) >= 0.35) || Can[5] == 0x02){    //ロボットの角度も判断材料
            //ここに開始点、中間点、終点の処理
            pc.printf("Caterpillar-on ");
            isCaterpillarLocked = false;
            caterpillarDown();  /*オムニ→キャタピラに切り替え*/
            stopOmni();
            isOmniLocked = true;
            while(slope <= END_ANGLE){pc.printf("1\n\r");if(Can[5] == 0x01){break;}}
            while(slope >= 3 || slope <= -3){pc.printf("2\n\r");if(Can[5] == 0x01){break;}}

        }
        else{
            pc.printf("Caterpillar-off ");
            isOmniLocked = false;
            caterpillarUp();
            isCaterpillarLocked = true;
            //後ろの超音波センサーの処理を削除
        }
        ThisThread::sleep_for(10);
    }
}

//-------ジャイロ用のオムニコード---------
void omniGyro(void){
    int i;
    int j;
    float count;
    double x,y;
    double speed;
    double angle;
    double omniPower[NUM_OMNI];
    double omniSpeed[NUM_OMNI];     //オムニpwmに書き込む値
    uint8_t forward;

    static bool flag_adjust = false;
    static float yaw_fixed = 0;
    bool lflag = false;
    bool rflag = false;

    x = (double)(Can[3]-64) / 64.0;
    y = (double)(-Can[4]+64) / 64.0;
    speed = sqrt(x*x + y*y);
    if(speed > MAX_OMNI_SPEED){
        speed = MAX_OMNI_SPEED;
    }
    angle = atan2(y, x);//ラジアンなので注意

#if 0
    if(x == 0){
            if(y >= 0){ angle = PI/2; }//ここがONだと右移動ができなくなる
            else{ angle = -PI/2; }
        }
    if( x < 0 ){ angle += PI; }
#endif


    omniPower[0] = cos(PI/4 - angle);
    omniPower[1] = cos(PI/4 + angle);
    omniPower[2] = cos(3*PI/4 + angle);
    omniPower[3] = cos(3*PI/4 - angle);

    if(Can[2] == 0x02 || Can[2] == 0x0a){
        for(i = 0; i < NUM_OMNI; i++){ omniSpeed[i] = omniPower[i] * speed; }

    }
    else{
        for(i = 0; i < NUM_OMNI; i++){ omniSpeed[i] = omniPower[i] * speed * MIN_OMNI_SPEED; }
    }

    if(isPressed(Can[2],2)){
        //左回転
        pc.printf("[roll left]\n\r");
        lflag = true;
        flag_adjust = false;
        for(i = 0; i < NUM_OMNI; i++){ Can[2] == 0x06 ? omniSpeed[i] = -MAX_ROLL_SPEED : omniSpeed[i] = -MIN_ROLL_SPEED; }
    }else{ lflag = false; }

    if(isPressed(Can[2], 4)){
        //右回転
        pc.printf("[roll right]\n\r");
        rflag = true;
        flag_adjust = false;
        for(i = 0; i < NUM_OMNI; i++){ Can[2]== 0x12 ? omniSpeed[i] = MAX_ROLL_SPEED : omniSpeed[i] = MIN_ROLL_SPEED; }
    }else{ rflag = false; }


    forward = forward & 0x00;
    for(i = 0; i < NUM_OMNI; i++){
        if(omniSpeed[i] > MAX_OMNI_SPEED){ omniSpeed[i] = MAX_OMNI_SPEED; }
        else if(omniSpeed[i] < -MAX_OMNI_SPEED){ omniSpeed[i] = -MAX_OMNI_SPEED; }

        if(omniSpeed[i] > 0){//ビットシフトで進行方向を保存
            omni_D[i] = 1;
            if(i != 3){
                forward++;
                forward = forward << 1;
            }else{
                forward++;
            }
            //pc.printf("1 ");
        }
        else if (omniSpeed[i] < 0){
            omni_D[i] = 0;
            if(i != 3){
                forward = forward << 1;
            }
            //pc.printf("0 ");//9.24後で戻す
            if(omniSpeed[i] <= -0.5){
                omniSpeed[i] += 0.07;//0.08
                pc.printf("<<-.->>");
            }else{
                omniSpeed[i] += 0.006;//0.007だと右にそれる10.3
            }
        }
    }

    if(!isOmniLocked){
        if((forward != forwardTmp) && (forward != 0)){
        //加速
            pc.printf("accel!!!! ");
            accelControl(&omniSpeed[0], 1);
        }
        else if((forward != forwardTmp) && (forward == 0)){
            //減速
            pc.printf("slow!!! ");
            accelControl(&omniSpeedTmp[0], 2);
        }
        else{
            for(i = 0; i < NUM_OMNI; i++){
                omni_P[i] = fabs(omniSpeed[i]);
            }
        }
    }
    for(i = 0; i < NUM_OMNI; i++){ omniSpeedTmp[i] = fabs(omniSpeed[i]); }
    forwardTmp = forward;

}

//配列に一気に書き込む
void accelControl(double *targetSpeed, int mode){
    int i;
    int countBreak;
    double pretime;
    double omniSpeed[NUM_OMNI];
    if(mode == 1){
        //加速
        timer_w.reset();
        timer_w.start();
        while(1){
            pretime = timer_w.read();
            for (i = 0; i < NUM_OMNI; i++) {
                omniSpeed[i] = targetSpeed[i] * (ACCEL_TIME * pretime);
                omni_P[i] = fabs(omniSpeed[i]);
                pc.printf("[%f] [%f] %f\n\r", targetSpeed[i], omniSpeed[i], ACCEL_TIME * pretime);
            }
            if(ACCEL_TIME*pretime >= 1){
                break;
            }
        }
        timer_w.stop();
    }
    else if(mode == 2){
        //減速
        countBreak = 0;
        timer_w.reset();
        timer_w.start();
        while(1){
            pretime = timer_w.read();
            for (i = 0; i < NUM_OMNI; i++) {
                if(omniSpeed[i] < 0 || fabs(targetSpeed[i]) < 0){
                    omni_P[i] = 0;
                    countBreak++;
                    break;
                }
                else if(maxNum(&omniSpeedTmp[0]) > 0.5){
                    omniSpeed[i] = 0.5 + (-ACCEL_TIME * pretime);
                    omni_P[i] = fabs(omniSpeed[i]);
                }
                else{
                    omniSpeed[i] = fabs(targetSpeed[i]) + (-ACCEL_TIME * pretime);
                    omni_P[i] = fabs(omniSpeed[i]);
                }
                pc.printf("[%f] [%f] %f\n\r", targetSpeed[i], omniSpeed[i], ACCEL_TIME * pretime);
            }
            if(ACCEL_TIME*pretime >= 1 || countBreak == 0){
                break;
            }
        }
        timer_w.stop();
    }
}

double maxNum(double *num){
    int i;
    double tmp = num[0];
    for(i = 1; i < NUM_OMNI; i++){
        if(num[i] > tmp){ tmp = num[i]; }
    }
    return tmp;
}

bool isPressed(unsigned char data, int bits){
    if((1 << bits & data) == 0){
        return false;
    }
    else{
        pc.printf("PRESS\n\r");
        return true;
    }
}
//---------------------------------------------------------




void initWheels(void){
    int i;

    initCan();                                      //CANを初期化
    Config();                                       //UART割り込みを設定

    for(i = 0; i < NUM_OMNI; i++){                  //オムニのpwm周期を設定
        omni_P[i].period_us(PERIOD_OMNI);
    }
    for(i = 0; i < NUM_UPDOWN; i++){                //パワーウィンドウのpwm周期設定
        updown_P[i].period_us(PERIOD_UPDOWN);
    }
    caterpillar_P.period_us(PERIOD_CATERPILLAR);    //キャタピラのpwm周期設定
    for (i = 0; i < NUM_LIMIT; i++){                //リミットスイッチをプルアップモードに
        limit[i].mode(PullUp);
    }
    pc.printf("set up wheels");
}


void omniAcceleration(void){
    int i;
    double pretime;
    double omniSpeed=0;

    if(CURRENT_OMNI_SPEED >= MAX_OMNI_SPEED){
        return;
    }

    timer_w.reset();
    timer_w.start();
    while(omniSpeed < MAX_OMNI_SPEED){
        pretime = timer_w.read();
        omniSpeed = 25 * pretime * pretime;
        for (i = 0; i < NUM_OMNI; i++) {
            omni_P[i] = omniSpeed;
        }
        pc.printf("time:%.2f up speed:%.2f\n\r",pretime,omniSpeed);
    }
    timer_w.stop();
    CURRENT_OMNI_SPEED = omniSpeed;
}

void omniSlowDown(void){
    int i,j;
    double pretime;
    double omniSpeed = CURRENT_OMNI_SPEED;

    if(CURRENT_OMNI_SPEED == 0){
        return;
    }
    pc.printf("omniSlowDown\n\r");

    timer_w.reset();
    timer_w.start();
    while(omniSpeed > 0){
        pretime = timer_w.read();
        omniSpeed = -25 * pretime * pretime + MAX_OMNI_SPEED;
        for (i = 0; i < NUM_OMNI; i++) {
            omni_P[i] = omniSpeed;
        }
        pc.printf("time:%.2f down speed:%.2f\n\r",pretime,omniSpeed);
    }
    timer_w.stop();
    CURRENT_OMNI_SPEED = omniSpeed;
}

inline void stopAllWheels(void){    //足回りを停止させる
    int i;

    for(i = 0; i < NUM_OMNI; i++){
        omni_P[i] = 0;
    }
    for(i = 0; i < NUM_UPDOWN; i++){
        updown_P[i] = 0;
    }
    caterpillar_P = 0;
    pc.printf("stop wheels");
}

inline void stopOmni(void){     //オムニを停止させる
    pc.printf("stop omni!\n\r");
    int i;
    for(i = 0; i < NUM_OMNI; i++){
            omni_P[i] = 0;
    }
}



void caterpillarDown(void){ //キャタピラ下げる

    if(!limit[1] && !limit[3]){ return; }
    timer_r.reset();
    timer_r.start();
    while(limit[1] || limit[3]){
        pc.printf("C Down\n\r");
        if(timer_r.read() >= CATERPILLAR_BREAK_TIME){ break; }
        updown_D[0] = 0;
        updown_D[1] = 0;
        updown_P[0] = MAX_UPDOWN_SPEED;
        updown_P[1] = MAX_UPDOWN_SPEED;
    }
    caterpiBreakTime = 0;
    timer_r.stop();
    updown_P[0] = 0;
    updown_P[1] = 0;
}


void caterpillarUp(void){   //キャタピラ上げる

    if((!limit[0] && !limit[2]) || caterpiBreakTime >= CATERPILLAR_BREAK_TIME){ return; }
    timer_r.reset();
    timer_r.start();
    while(limit[0] || limit[2]){
        pc.printf("C UP\n\r");
        if(timer_r.read() >= CATERPILLAR_BREAK_TIME){ break; }
        updown_D[0] = 1;
        updown_D[1] = 1;
        updown_P[0] = MIN_UPDOWN_SPEED;
        updown_P[1] = MIN_UPDOWN_SPEED;
    }
    caterpiBreakTime = timer_r.read();
    timer_r.stop();
    updown_P[0] = 0;
    updown_P[1] = 0;
}

void omniMovedByJetson(void){       //Jetsonからの通信で足回り動かす
    if(JETSON[0] != 0x80){return;}  //信号が来ていなければreturn
    //------
    int i;
    if(JETSON[1] == 0x01){
        if(JETSON[3] == 0x01){
            omni_D[0] = 1;
            omni_D[1] = 1;
            omni_D[2] = 1;
            omni_D[3] = 1;
            omniAcceleration();
            //setOmniPwm(0.1);//値がずっと0.1になる
        }
        else if(JETSON[3] == 0x02){
            omni_D[0] = 0;
            omni_D[1] = 0;
            omni_D[2] = 0;
            omni_D[3] = 0;
            omniAcceleration();
            //setOmniPwm(0.1);
        }
        else if(JETSON[2] == 0x01){
            omni_D[0] = 1;
            omni_D[1] = 0;
            omni_D[2] = 0;
            omni_D[3] = 1;
            omniAcceleration();
        }
        else if(JETSON[2] == 0x02){
            omni_D[0] = 0;
            omni_D[1] = 1;
            omni_D[2] = 1;
            omni_D[3] = 0;
            omniAcceleration();
        }
        else if(JETSON[2] == 0x04){
            omni_D[0] = 0;
            omni_D[1] = 0;
            omni_D[2] = 1;
            omni_D[3] = 1;
            omniAcceleration();
        }
        else if(Can[5] == 0x08){
            omni_D[0] = 1;
            omni_D[1] = 1;
            omni_D[2] = 0;
            omni_D[3] = 0;
            omniAcceleration();
        }
        else{
            omniSlowDown();
        }

    }

    else if(JETSON[1] == 0x02){//0x02はストップ
        //stop
        omniSlowDown();
    }
}


void initCan(void){
    can.reset();
    can.frequency(500000);
    can.filter(CAN_WHEEL_ID, 0xfff, CANStandard, 0);
}


//割り込み１
inline void Config(void){
    //初期設定
    jetson.attach(&JetsonData, Serial::RxIrq);
    can.attach(&canData, CAN::RxIrq);
}

//割り込み２
inline void JetsonData(void){
    //受信割り込みのときに来るよ
    int JETSON_Data = jetson.getc();
    static int bits = 0;

    if(JETSON_Data == 128){
        bits = 0;
    }

    if (JETSON_Data >= 0){
        JETSON[bits] = JETSON_Data;

        if (bits == 7){
            bits = 0;
        }
        else {
            bits++;
        }
    }
}

//割り込み3
void canData(void){
    can.read(msg);
    if(can.rderror() != 0){
        can.reset();
    }
    if(msg.id == CAN_WHEEL_ID){
        //Can = msg.data; //CAN[]にデータを代入
        for(int i = 0; i < CAN_SIZE; i++){
            Can[i] = msg.data[i];
        }
        switch(Can[7]){
            case 0:
                yaw = Can[6];
                slope = Can[1];
                break;
            case 1:
                yaw = Can[6] * -1;
                slope = Can[1];
                break;
            case 2:
                yaw = Can[1];
                slope = Can[1] * -1;
                break;
            case 3:
                yaw = Can[6] * -1;
                slope = Can[1] * -1;
                break;
        }

        led[2] = !led[2];
    }
    else{
        //Can = NULL;
        led[2] = 0;
    }
}

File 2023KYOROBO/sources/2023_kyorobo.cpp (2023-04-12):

/*
 *2023_Kyorobo_ver2
 *2023年九州共同ロボコン　沖縄高専美らヤドカリーズ　ソースコード
 *
 *ver3の変更点:
 *出来るだけコード整形した完成版(のはず)
 *
 *Tips:
 *ボーレートは115200
 *
 *
*/

#include "mbed.h"
#include "rtos.h"
#include "RotaryEncoder.h"
#include "servo.h"
#include "math.h"



/******定数(define)******/
#define MAX_ROLL_SPEED 0.5          //ガチャ盤の速度を制限
#define MAX_UPDOWN_SPEED 0.4        //ガチャが上下のする速度
#define MAX_OMUNI_SPEED 0.2
#define MAX_ARM1_SPEED 0.4
#define MAX_ARM2_SPEED 0.4
#define MAX_CUP_SPEED 0.5
#define M_PI 3.14159265358979323846


/******定数(const)******/
const uint32_t TIMEOUT_MS = 5000;           //watchdogタイマのタイムリミット
//const float MAX_OMUNI_SPEED = 0.4;


/******関数宣言******/
inline void Config(void);
inline void PS3Data(void);
void gatya_roll(void);          //ガチャガチャを回す関数
void gatya_updown(void);        //ガチャガチャを昇降・下降させる
void cup_updown(void);
void kick_wd(void);             //watchdogタイマをキックする
//void MoveOmni(void);          //スレッド化したので一旦コメントアウト3.2.2023
void OmniPWM(int speed);
void setup_PWM(void);
void move_arm1(void);//ユンボ動かす
void move_arm2(void);//UFOキャッチャー動かす
float calc_Rightjoyangle(void);//右joysticの角度を算出
float calc_Leftjoyangle(void);//左joysticの角度を算出
void MoveServo(void);//サーボ動かす



/******PIN宣言******/
RawSerial pc(USBTX,USBRX);              //シリアル通信
RawSerial cont(PC_10, PC_11, 2400);      //SBXBT用。ボーレートを2400に設定
RotaryEncoder R1(PA_0, PA_1);           //ガチャガチャのエンコーダ
DigitalOut motor(PC_0);
PwmOut motor_p(PA_10);//PC_7でチャンネルがかぶってたので変更


//足回り(オムニ)digitalout
DigitalOut D_omuni[4] = {
    DigitalOut(PC_5),
    DigitalOut(PB_12),
    DigitalOut(PB_9),
    DigitalOut(PB_8)
    };

//足回り(オムニ)PwmOut
PwmOut P_omuni[4] = {
    PwmOut(PB_4),//捨てピン//PB_10
    PwmOut(PB_5),
    PwmOut(PC_8),
    PwmOut(PC_9)
    };
PwmOut P_omuni0(PC_6);


DigitalOut motorD_updown(PC_2);     //ガチャ昇降用モーター
PwmOut motorP_updown(PB_7);         //上に同じ

DigitalOut cupD_updown(PC_4);       //カップ昇降用モーター
PwmOut cupP_updown(PA_11);

DigitalIn limit[2] = {
    DigitalIn(PC_13),               //下：リミットスイッチ(PC_13はどうせユーザースイッチだから)
    DigitalIn(PA_15)                //上：PC_14は使えないピンだった;_;
};

DigitalOut motorD_arm1(PA_7);               //ユンボー
PwmOut motorP_arm1(PB_6);
DigitalOut motorD_arm2(PA_9);                   //UFOキャッチャーのモーター
PwmOut motorP_arm2(PA_8);
servo servo_arm2(PB_10);                    //PB_4から変更//UFOキャッチャーのサーボ

DigitalOut led(PA_4);


/******グローバル変数******/
int PS3[7];         //PS3コントローラーの電文格納変数
int countL1;    //L1スイッチのカウンタ

Timer timer;
Thread thread;


//関数だとうまくいかなかったのでスレッドにした
void MoveOmni(){
    pc.printf("omnistart!\n\r");
    P_omuni0.period_us(1275);           //オムニ
    P_omuni[1].period_us(1275);
    P_omuni[2].period_us(1275);
    P_omuni[3].period_us(1275);
    //float speed;
    //float *p;
    //p = &speed;
    float angle;
    while(1){
        angle = calc_Rightjoyangle();


        if(PS3[1] == 0x10){
            if(angle > -22.5 && angle <= 22.5){
                D_omuni[0] = 0;//右に進む
                D_omuni[1] = 0;
                D_omuni[2] = 0;
                D_omuni[3] = 0;
                pc.printf(" Rolling_RIGHT ");
                OmniPWM(1);
            }
            else if(angle > 157.5  && angle <= -157.5 || angle == 180){
                D_omuni[0] = 1;//左に進む
                D_omuni[1] = 1;
                D_omuni[2] = 1;
                D_omuni[3] = 1;
                pc.printf(" Rolling_LEFT ");
                OmniPWM(1);
            }
            else{
                //pc.printf(" ELSE ");
                OmniPWM(0);
            }
        }


        else{
            if(angle > -22.5 && angle <= 22.5 || angle == 0){
                
                D_omuni[1] = 0;
                D_omuni[2] = 0;
                D_omuni[3] = 1;
                D_omuni[0] = 1;//右に進む
                pc.printf(" RIGHT \n\r");
                OmniPWM(1);
            }
            
            else if(angle > 67.5 && angle <= 112.5){
                
                D_omuni[1] = 0;
                D_omuni[2] = 1;
                D_omuni[3] = 1;
                D_omuni[0] = 0;//前に進む
                pc.printf(" GO \n\r");
                OmniPWM(1);
            }
            
            else if(angle > 157.5  && angle <= -157.5 || angle == 180){
                
                D_omuni[1] = 1;
                D_omuni[2] = 1;
                D_omuni[3] = 0;
                D_omuni[0] = 0;//左に進む
                pc.printf(" LEFT \n\r");
                OmniPWM(1);
            }
            
            else if(angle > -112.5 && angle <= -67.5){
                
                D_omuni[1] = 1;
                D_omuni[2] = 0;
                D_omuni[3] = 0;
                D_omuni[0] = 1;//後ろに進む
                pc.printf(" BACK \n\r");
                OmniPWM(1);
            }
            else{
            //pc.printf(" ELSE ");
                OmniPWM(0);
            }
        }
        //pc.printf("\r");
    }
}


void cup_updown(void){
    //pc.printf(" cup_updown\n\r ");
    /*int L[2];
    L[0] = limit[0];
    L[1] = limit[1];*/
    //pc.printf(" %d %d ",L[0],L[1]);
    //pc.printf(" cup_updown ");
        if (PS3[1] == 0x01){
            while(1){
                pc.printf(" cup_updown\n\r");
                while(limit[1] == 1){
                    pc.printf("cup up!!\n\r");
                    cupD_updown = 0;
                    cupP_updown = MAX_CUP_SPEED;
                }
            //if(limit[0] == 1 && limit[1] == 0)
                while(limit[0] == 1){
                    pc.printf("cup down!!\n\r");
                    cupD_updown = 1;
                    cupP_updown = MAX_CUP_SPEED;
                }
            
            cupP_updown = 0;
            pc.printf(" cup_def!! ");
            break;
            }

            
            
        kick_wd();
        }
    
}
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

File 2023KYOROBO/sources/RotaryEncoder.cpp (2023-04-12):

#include "RotaryEncoder.h"

RotaryEncoder::RotaryEncoder(PinName PIN_A, PinName PIN_B) : _PIN_A(PIN_A), _PIN_B(PIN_B)
{
    count = 0;
    pos = 0;
    
    _PIN_A.mode(PullUp);
    _PIN_A.rise(this, &RotaryEncoder::Proccessing);
    _PIN_A.fall(this, &RotaryEncoder::Proccessing);
    
    _PIN_B.mode(PullUp);
    _PIN_B.rise(this, &RotaryEncoder::Proccessing);
    _PIN_B.fall(this, &RotaryEncoder::Proccessing);
}

//エンコーダの処理部分
void RotaryEncoder::Proccessing(void)
{
    unsigned char D = (!(_PIN_B.read()) << 1) + (!(_PIN_A.read()));
    unsigned char old_data = pos & 3;
    unsigned char new_data = (pos & 48) >> 4;
    
    if (D == 3){
        D = 2;
    }
    else if (D == 2){
        D = 3;
    }
    
    if (D != old_data){
        if (new_data == 0){
            if (D == 1 || D == 3){
                new_data = D;
            }
        }
        else {
            if (D == 0){
                if (new_data == 1 && old_data == 3){
                    count++;
                }
                else if (new_data == 3 && old_data == 1){
                    count--;
                }
                new_data = 0;
            }
        }
        pos = (new_data << 4) + (old_data << 2) + D;
    }
}

//エンコーダのカウントのリセット
void RotaryEncoder::Reset(void)
{
    count = 0;
}

//エンコーダのカウントの表示
int RotaryEncoder::Get_Count(void)
{
    return (count);
}

//円周の表示
double RotaryEncoder::Get_Circumference(int Diameter, int Resolution)
{
    return (Diameter * 3.14 * ((double)count / Resolution));
}
